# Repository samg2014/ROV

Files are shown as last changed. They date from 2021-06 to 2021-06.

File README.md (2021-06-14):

##*About This Project*
This respository is for all files related to modifications of the [Sea Perch](www.seaperch.org) ROV. The overall goals of this project are to:
* Make the vehicle controllable from a microcontroller or computer.
* Enable the vehicle to have the potential to be self contained. This includes:
  * Making the controller waterproof so it can be deployed on the vehicle,
  * Making the battery waterproof so it can go on the vehicle,
  * Writing autonomy scripts for the vehicle.
* Make the vehicle 'smart', including:
  * Autonomy, regardless of controller location (land or vehicle)
  * Sensor integration (IMUs...)
* Anything else we think of as we go.

##*Organization*
###Software Directory
The Software directory houses all of the code, Arduino or otherwise, associated with this project. It have two main subdirectories: Vehicle and Computer.
####Vehicle
The Vehicle subdirectory is for all sketches that are to be uploaded to the vehicle controller Arduino.
####Computer
The Computer subdirectory is for all support software that may exist. This could potentially be remote interfaces, wireless command sequence uploaders, command generators and much more.
###Electrical Directory
The Electrical directory is for schematics eagle design files and related to designing the vehicle controller. Additionally it should include parts lists and assembly processes if applicable.
###Hardware Directory
The Hardware Design directory is for potential CAD design files for the main structure of the vehicle.

##*Resources*
* [Google Drive folder](https://drive.google.com/folderview?id=0B45sdQ03G0k-UUpMSS1selFKa1k&usp=sharing) 
* [Sea Perch](www.seaperch.org) 
* [Sea Perch BOM](http://www.seaperch.org/Parts_List) (Note: requires free account) 
* [Sparkfun](www.sparkfun.com) (Parts)

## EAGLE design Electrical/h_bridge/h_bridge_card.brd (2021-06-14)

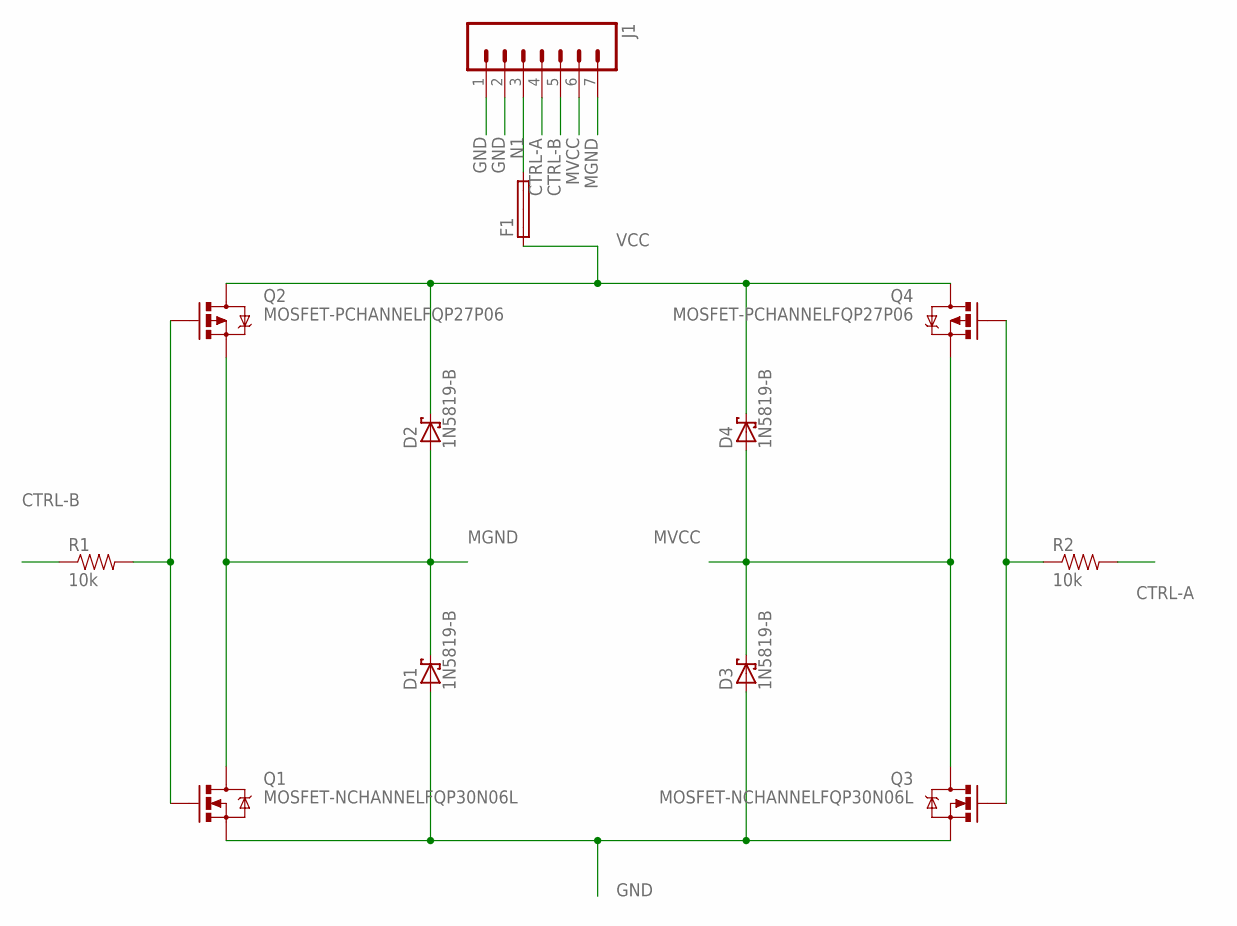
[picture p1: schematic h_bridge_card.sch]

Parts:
D1, D2, D3, D4: 1N5819-B; DO41-7.6
F1: SHK20L
J1: M07LOCK; 1X07_LOCK
Q1, Q3: MOSFET-NCHANNELFQP30N06L; TO220V
Q2, Q4: MOSFET-PCHANNELFQP27P06; TO220V
R1, R2: 10k; AXIAL-0.3

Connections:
CTRL-A: J1.4, R2.P$2 (2)
CTRL-B: J1.5, R1.P$1 (1)
GND: D1.A, D3.A, J1.1, J1.2, Q1.3 (S), Q3.3 (S)
MGND: D1.C, D2.A, J1.7, Q1.2 (D), Q2.3 (S)
MVCC: D3.C, D4.A, J1.6, Q3.2 (D), Q4.3 (S)
N1: F1.2A, J1.3
unnamed: Q3.1 (G), Q4.1 (G), R2.P$1 (1)
unnamed: Q1.1 (G), Q2.1 (G), R1.P$2 (2)
VCC: D2.C, D4.C, F1.1A, Q2.2 (D), Q4.2 (D)

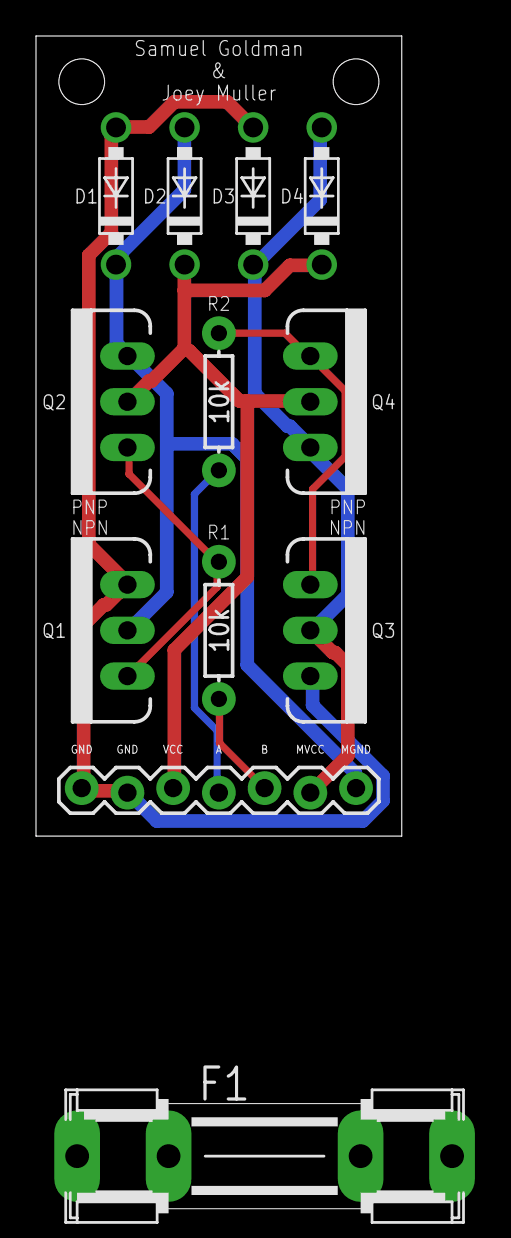
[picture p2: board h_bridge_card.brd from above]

Board: 2 copper layers, 20.3 x 44.5 mm, 12 parts (0 on the bottom side), 9 nets.

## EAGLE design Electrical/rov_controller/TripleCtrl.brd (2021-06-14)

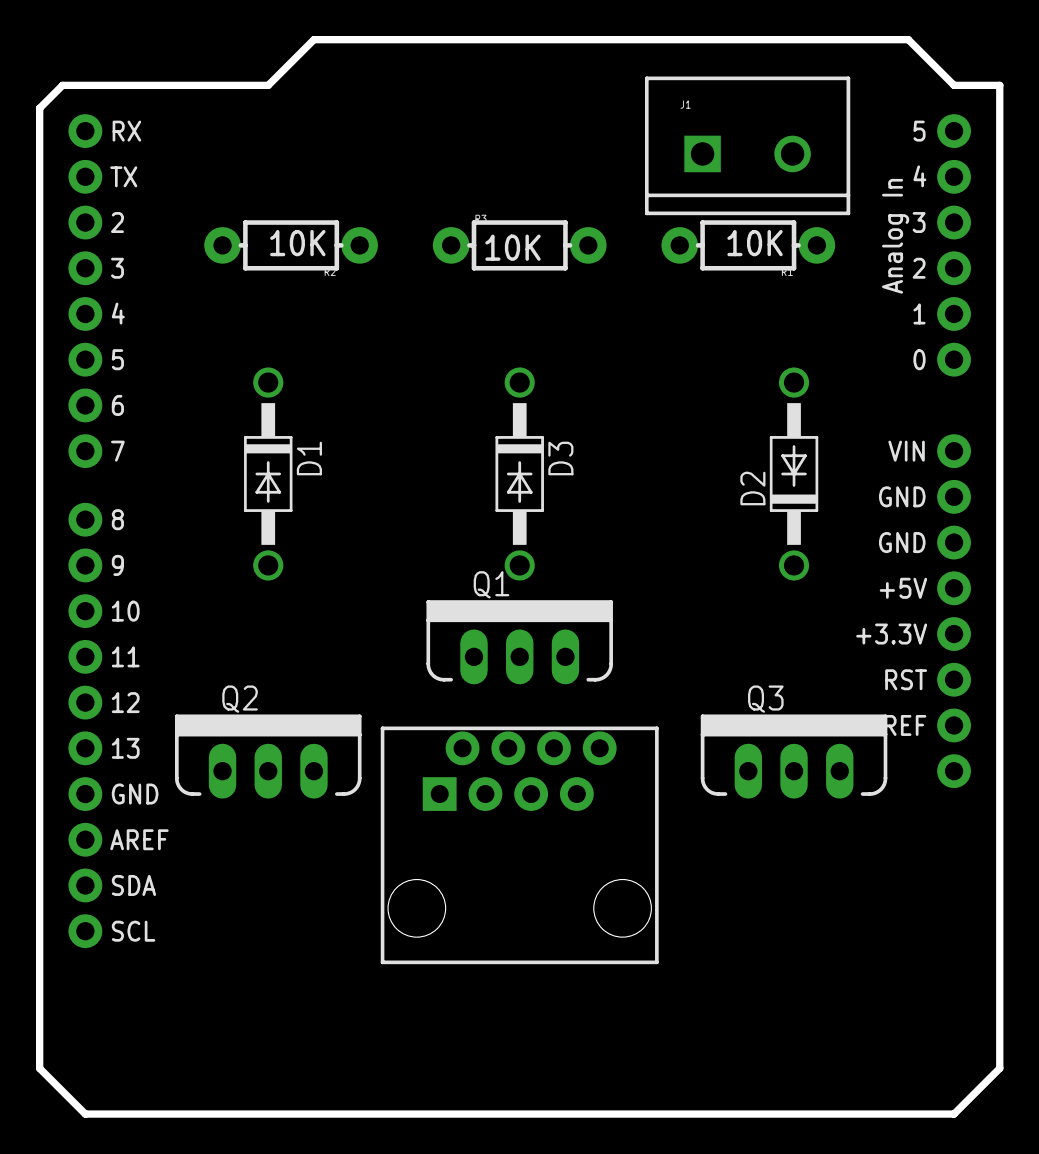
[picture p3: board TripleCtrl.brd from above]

Board: 2 copper layers, 53.3 x 59.7 mm, 12 parts (0 on the bottom side), 8 nets.

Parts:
D1, D2, D3: BA340A; DO41-10
J1: SCREWTERMINAL-5MM-2
J2: ARDUINO_R3_SHIELD; UNO_R3_SHIELD
J3: RJ45; RJ45-8
Q1, Q2, Q3: MOSFET-NCHANNELFQP30N06L; TO220V
R1, R2, R3: 10K; AXIAL-0.3-KIT

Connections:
unnamed: D1.C, D2.C, D3.C, J1.1, J3.1, J3.3, J3.4
unnamed: J1.2, J2.GND@0, Q1.3, Q2.3, Q3.3, R1.P$1, R2.P$1, R3.P$1
unnamed: D1.A, J3.2, Q1.2
unnamed: J2.D11, Q1.1, R1.P$2
unnamed: D2.A, J3.6, Q2.2
unnamed: D3.A, J3.5, Q3.2
unnamed: J2.D10, Q3.1, R3.P$2
unnamed: J2.D9, Q2.1, R2.P$2

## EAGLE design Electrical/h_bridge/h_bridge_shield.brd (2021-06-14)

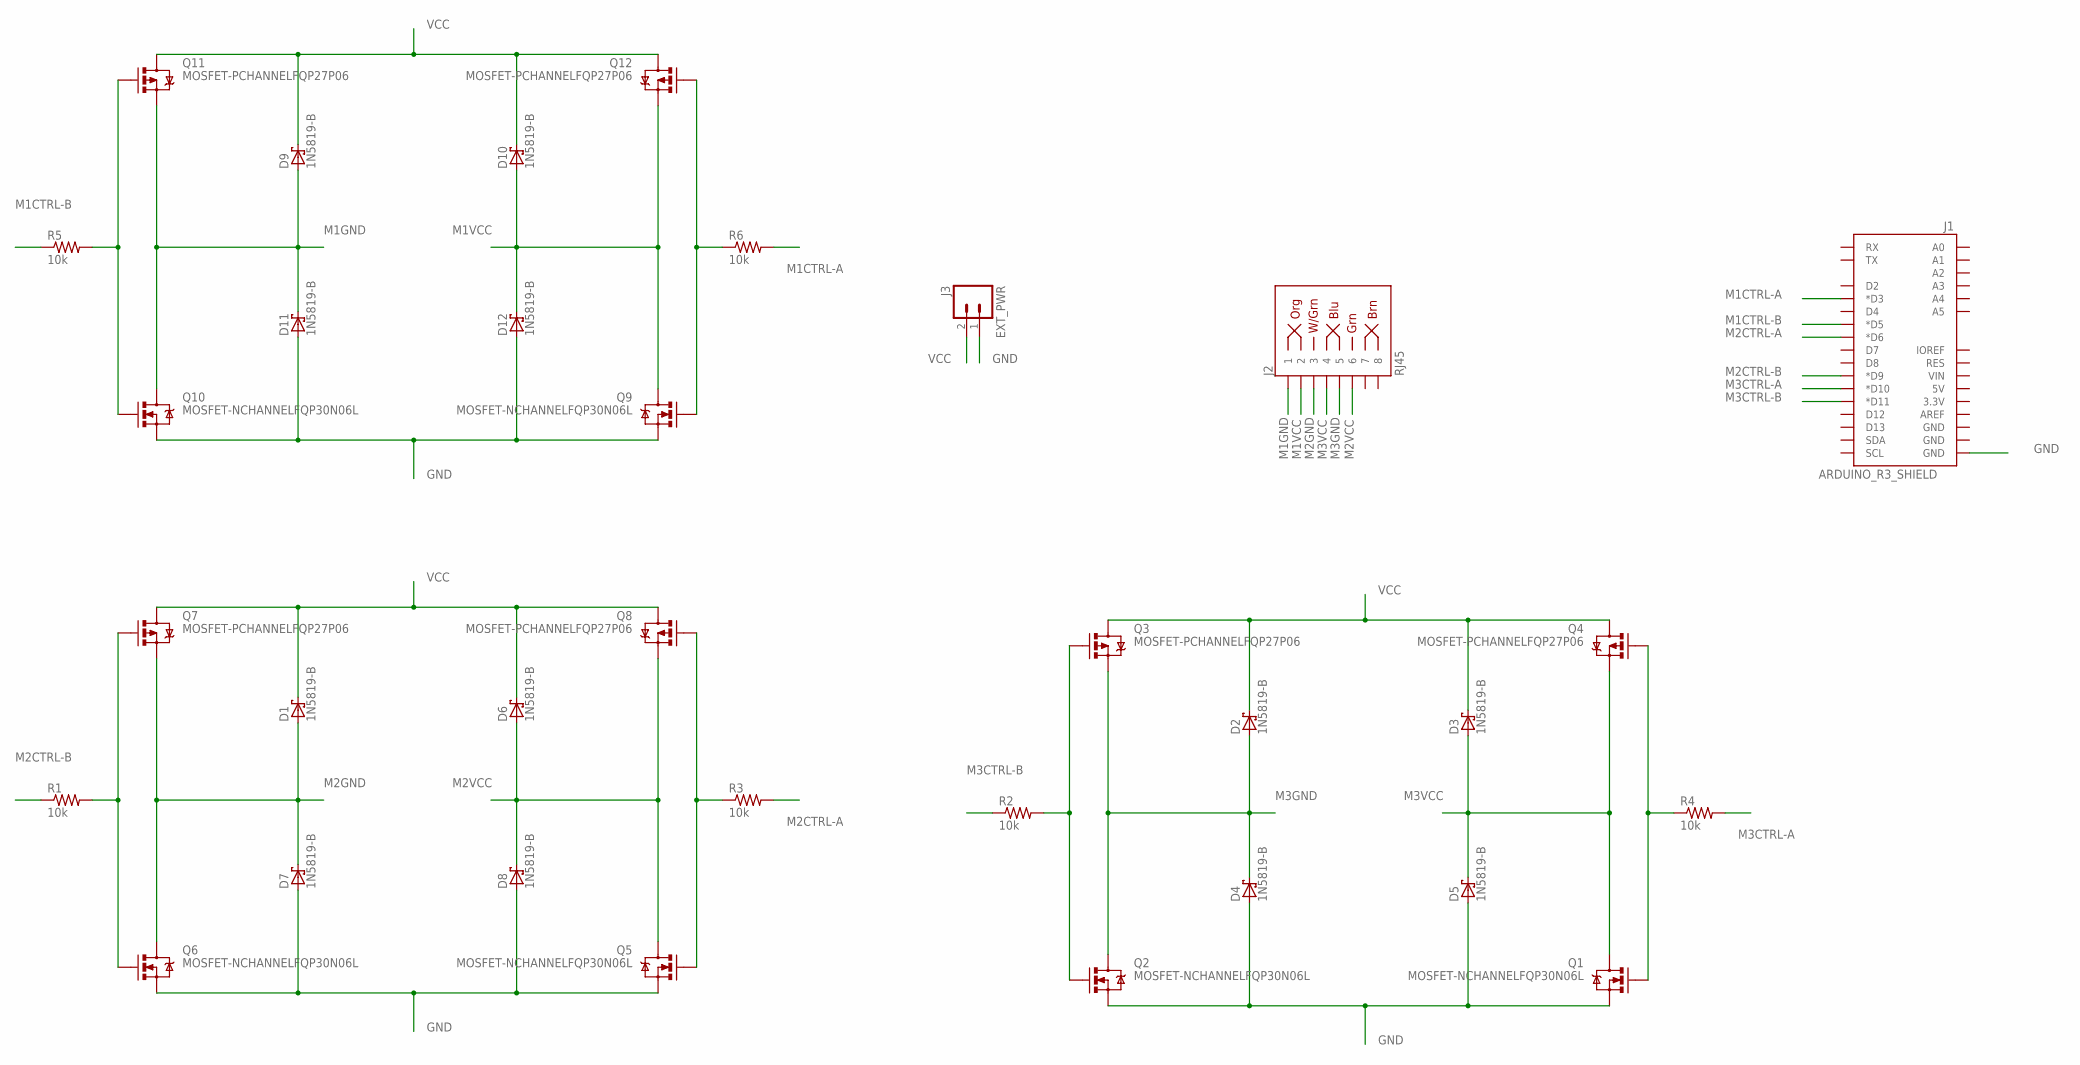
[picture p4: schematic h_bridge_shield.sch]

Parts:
D1, D2, D3, D4, D5, D6, D7, D8, D9, D10, D11, D12: 1N5819-B; DO41-7.6
J1: ARDUINO_R3_SHIELD; UNO_R3_SHIELD
J2: RJ45; RJ45-8
J3: EXT_PWR; JST-2-PTH-VERT
Q1, Q2, Q5, Q6, Q9, Q10: MOSFET-NCHANNELFQP30N06L; TO220V
Q3, Q4, Q7, Q8, Q11, Q12: MOSFET-PCHANNELFQP27P06; TO220V
R1, R2, R3, R4, R5, R6: 10k; AXIAL-0.3

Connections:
GND: D4.A, D5.A, D7.A, D8.A, D11.A, D12.A, J1.GND@0 (GND), J3.1, Q1.3 (S), Q2.3 (S), Q5.3 (S), Q6.3 (S), Q9.3 (S), Q10.3 (S)
M1CTRL-A: J1.D3 (*D3), R6.P$2 (2)
M1CTRL-B: J1.D5 (*D5), R5.P$1 (1)
M1GND: D9.A, D11.C, J2.1, Q10.2 (D), Q11.3 (S)
M1VCC: D10.A, D12.C, J2.2, Q9.2 (D), Q12.3 (S)
M2CTRL-A: J1.D6 (*D6), R3.P$2 (2)
M2CTRL-B: J1.D9 (*D9), R1.P$1 (1)
M2GND: D1.A, D7.C, J2.3, Q6.2 (D), Q7.3 (S)
M2VCC: D6.A, D8.C, J2.6, Q5.2 (D), Q8.3 (S)
M3CTRL-A: J1.D10 (*D10), R4.P$2 (2)
M3CTRL-B: J1.D11 (*D11), R2.P$1 (1)
M3GND: D2.A, D4.C, J2.5, Q2.2 (D), Q3.3 (S)
M3VCC: D3.A, D5.C, J2.4, Q1.2 (D), Q4.3 (S)
unnamed: Q5.1 (G), Q8.1 (G), R3.P$1 (1)
unnamed: Q6.1 (G), Q7.1 (G), R1.P$2 (2)
unnamed: Q9.1 (G), Q12.1 (G), R6.P$1 (1)
unnamed: Q10.1 (G), Q11.1 (G), R5.P$2 (2)
unnamed: Q1.1 (G), Q4.1 (G), R4.P$1 (1)
unnamed: Q2.1 (G), Q3.1 (G), R2.P$2 (2)
VCC: D1.C, D2.C, D3.C, D6.C, D9.C, D10.C, J3.2, Q3.2 (D), Q4.2 (D), Q7.2 (D), Q8.2 (D), Q11.2 (D), Q12.2 (D)

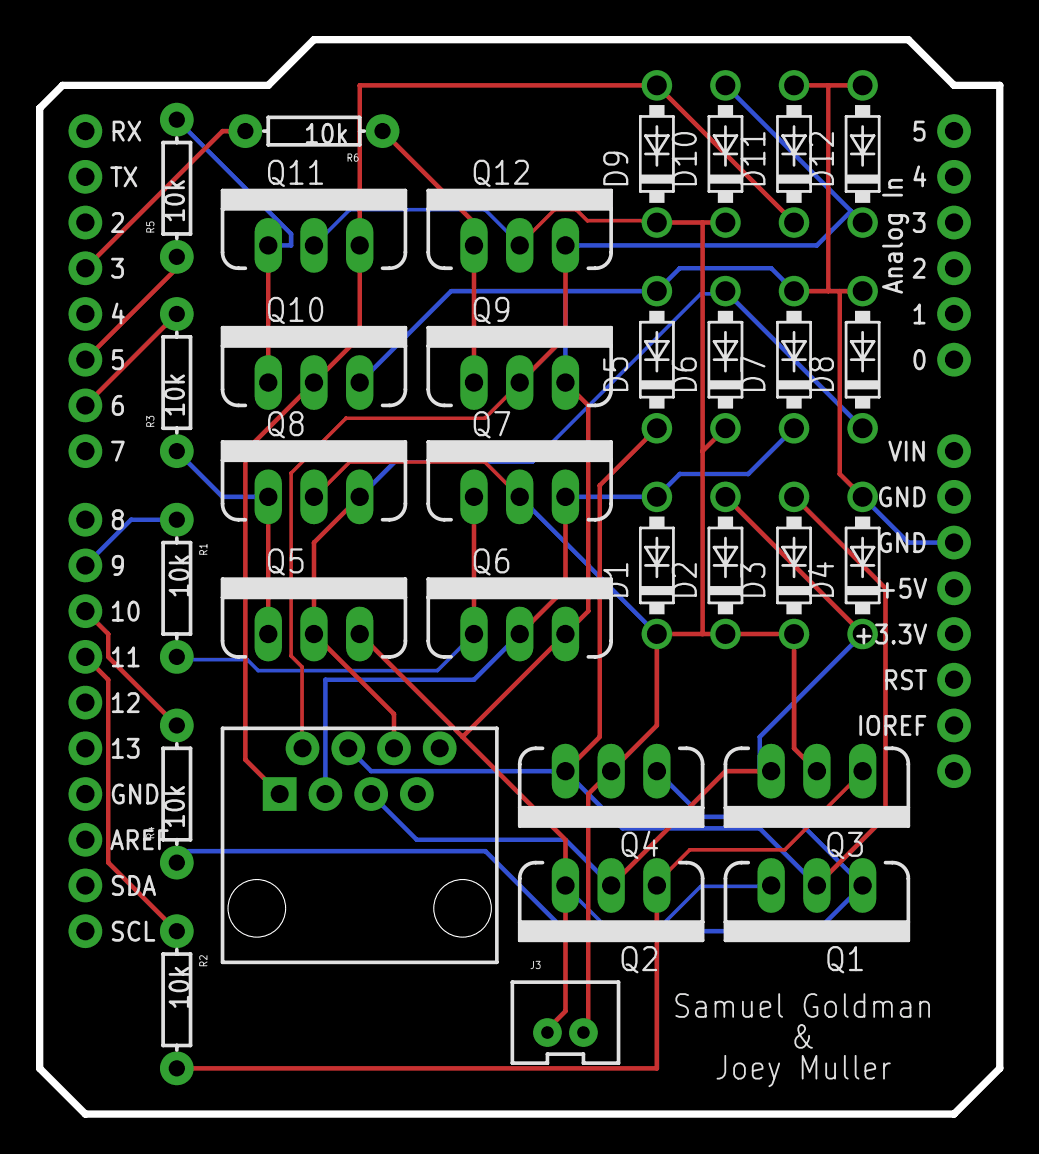
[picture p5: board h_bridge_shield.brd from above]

Board: 2 copper layers, 53.3 x 59.7 mm, 33 parts (0 on the bottom side), 20 nets.

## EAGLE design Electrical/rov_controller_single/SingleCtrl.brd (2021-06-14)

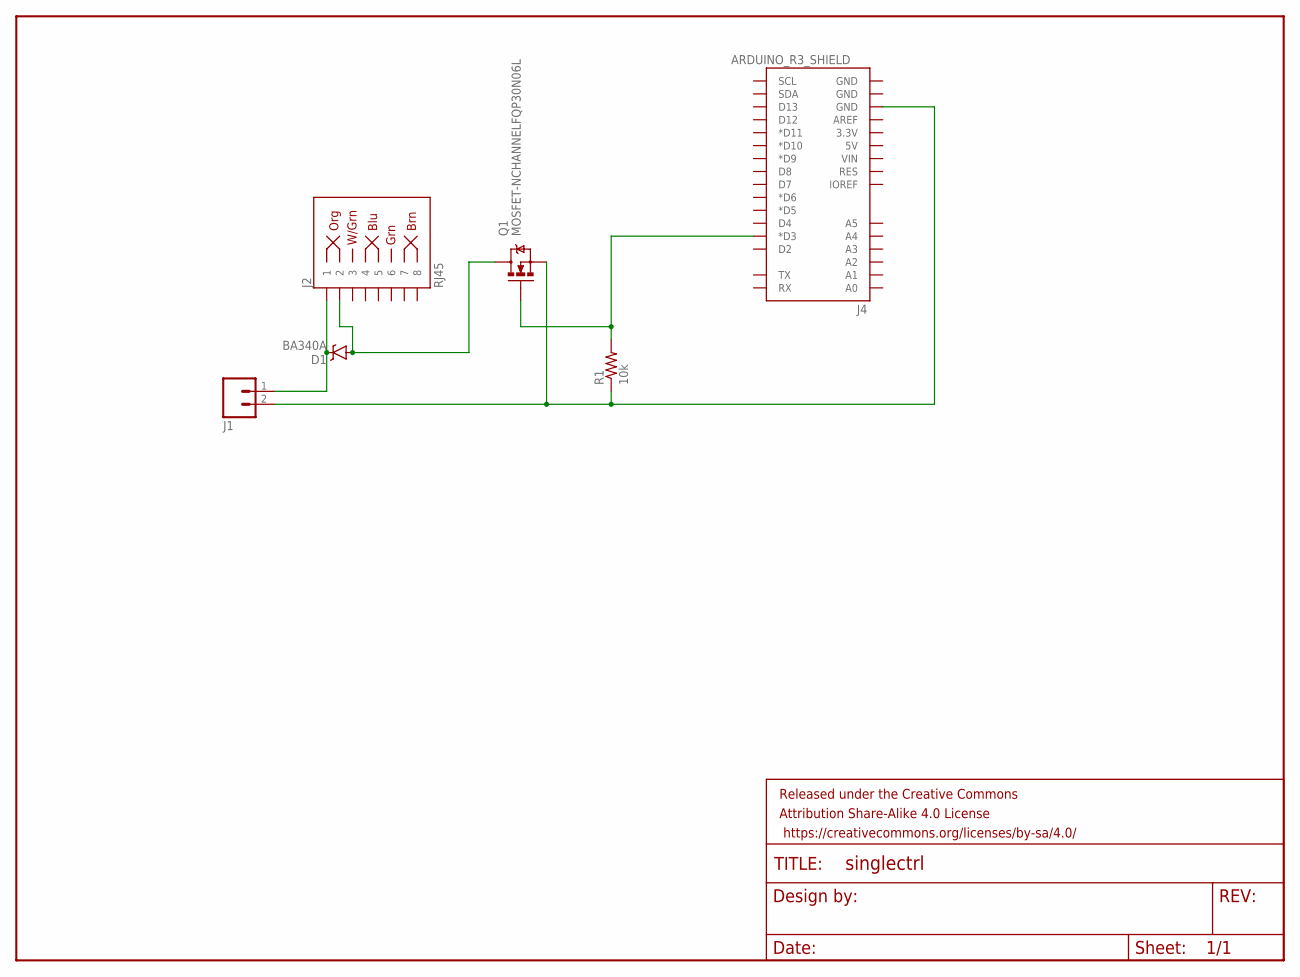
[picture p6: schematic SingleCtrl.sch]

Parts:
D1: BA340A; SMA-DIODE
FRAME1: FRAME-LETTER; CREATIVE_COMMONS
J1: M02JST-PTH-2; JST-2-PTH
J2: RJ45; RJ45-8
J4: ARDUINO_R3_SHIELD; UNO_R3_SHIELD
Q1: MOSFET-NCHANNELFQP30N06L; TO220V
R1: 10k; AXIAL-0.3

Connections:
unnamed: D1.C, J1.1, J2.1
unnamed: D1.A, J2.2, Q1.2 (D)
unnamed: J1.2, J4.GND@2 (GND), Q1.3 (S), R1.P$1 (1)
unnamed: J4.D3 (*D3), Q1.1 (G), R1.P$2 (2)

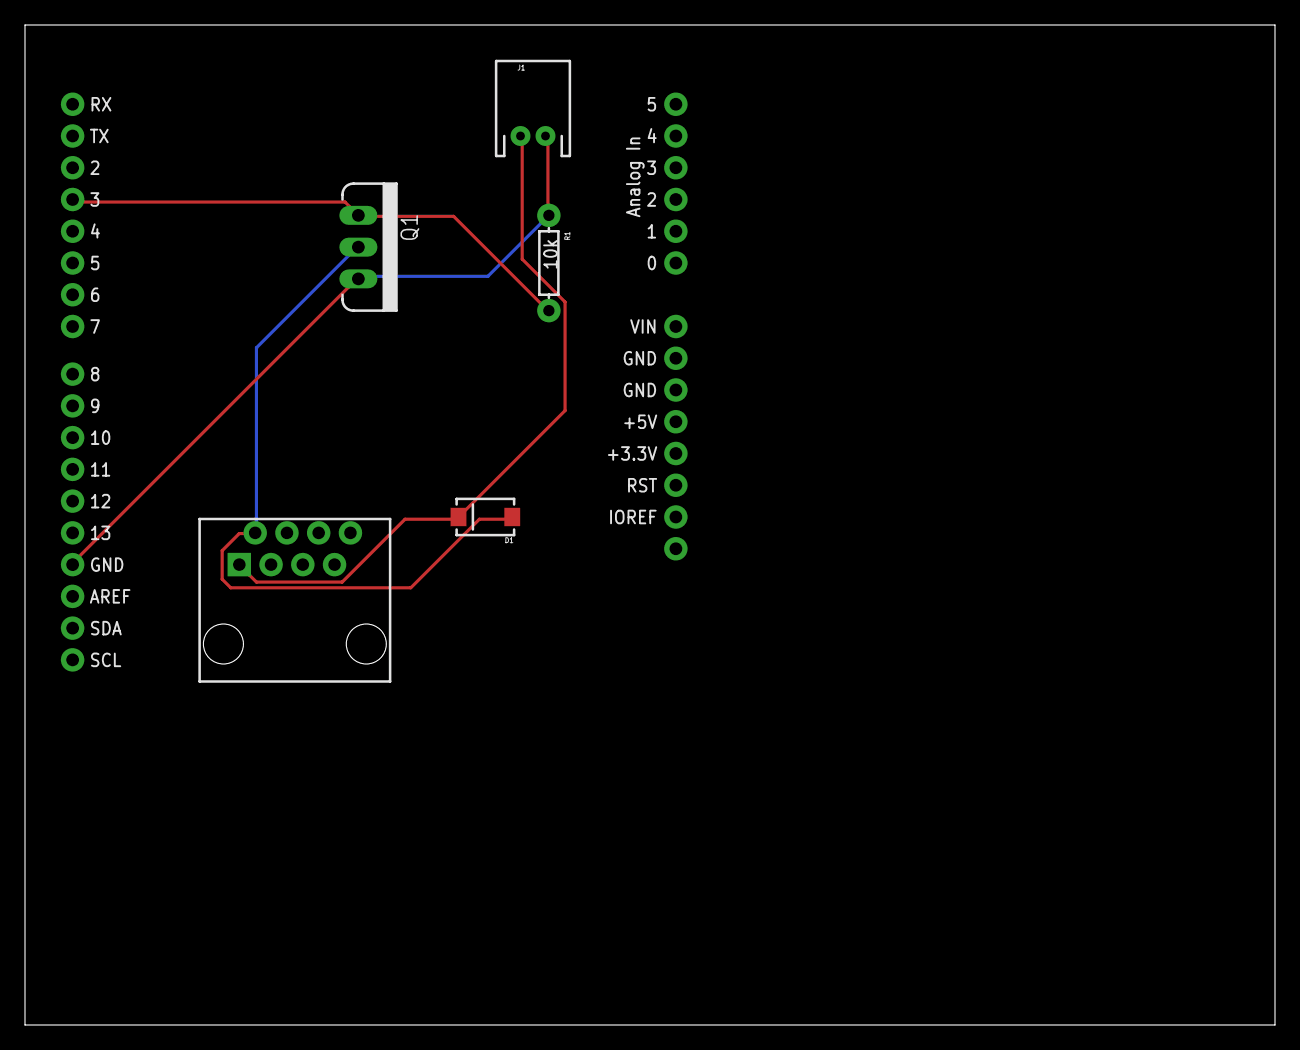
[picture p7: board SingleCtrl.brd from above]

Board: 2 copper layers, 100.0 x 80.0 mm, 7 parts (0 on the bottom side), 4 nets.

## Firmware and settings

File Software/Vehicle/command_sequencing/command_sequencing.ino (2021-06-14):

/**
   FILE NAME: command_sequencing
   AUTHOR: Samuel Goldman
   PURPOSE: run the vehicle by sending a sequence of commands
            to be run later.
*/

String inputString = "";         // a string to hold incoming data
boolean stringComplete = false;  // whether the string is complete

// Flags to determine what run mode the vehicle is in
bool EDIT_MODE = false;
bool RUN_NORM = false;
bool RUN_DEBUG = false;

// A list of commands to be executed
String COMMANDS[50];
int COMMANDS_LENGTH = 0; // How many commands are actually in the list

// Index to execute now
int EXECUTE_INDEX = -1;

void setup() {
  // initialize serial:
  Serial.begin(9600);

  // reserve 200 bytes for the inputString:
  inputString.reserve(200);

  // Setup pins for motor control
  pinMode(9, OUTPUT);
  pinMode(10, OUTPUT);
  pinMode(11, OUTPUT);
}

void loop() {
  // Handle new input
  if (stringComplete) {

    // Enter edit mode if possible
    if (inputString == "--edit") {
      if (RUN_NORM == true || RUN_DEBUG == true) {
        Serial.println("The program is running. To edit it, run '--halt'.");
      } else if (EXECUTE_INDEX != -1) {
        Serial.println("The program is paused. To edit it, run '--halt'.");
      } else {
        EDIT_MODE = true;
        Serial.println("Entering program editer...");
      }
    }

    // Quit the command sequence editor
    if (inputString == "--quit") {
      EDIT_MODE = false;
      Serial.println("Exiting program editer...");
    }

    // Handle the execute command
    if (inputString.startsWith("--execute")) {
      if (EDIT_MODE == true) {
        Serial.println("In edit mode, cannot execute now!");
      }
      else if (RUN_NORM == true) {
        Serial.println("Already running normally!");
      }
      else if (RUN_DEBUG == true) {
        Serial.println("Already running in debug mode!");
      }
      else {
        int index = inputString.indexOf(" ");
        if (index == -1) {
          if (EXECUTE_INDEX == -1)
            EXECUTE_INDEX = 0;
          Serial.println((String)"Starting execution at index=" + EXECUTE_INDEX + "...");
          RUN_NORM = true;
        }
        else {
          int temp = inputString.substring(index + 1).toInt();
          if (temp > COMMANDS_LENGTH - 1) {
            Serial.println("Starting index out of bounds!");
          } else {
            EXECUTE_INDEX = temp;
            Serial.println((String)"Starting execution at index=" + EXECUTE_INDEX + "...");
            RUN_NORM = true;
          }
        }
      }
    }

    // Execute commands in debug mode
    if (inputString.startsWith("--debug")) {
      if (EDIT_MODE == true) {
        Serial.println("In edit mode, cannot execute now!");
      }
      else if (RUN_NORM == true) {
        Serial.println("Already running normally!");
      }
      else if (RUN_DEBUG == true) {
        Serial.println("Already running in debug mode!");
      }
      else {
        int index = inputString.indexOf(" ");
        if (index == -1) {
          if (EXECUTE_INDEX == -1)
            EXECUTE_INDEX = 0;
          Serial.println((String)"Starting execution at index=" + EXECUTE_INDEX + "...");
          RUN_DEBUG = true;
        }
        else {
          int temp = inputString.substring(index + 1).toInt();
          if (temp > COMMANDS_LENGTH - 1) {
            Serial.println("Starting index out of bounds!");
          } else {
            EXECUTE_INDEX = temp;
            Serial.println((String)"Starting execution at index=" + EXECUTE_INDEX + "...");
            RUN_DEBUG = true;
          }
        }
      }
    }

    if (inputString == "--halt") {
      Serial.println("Halting execution...");
      RUN_NORM = false;
      RUN_DEBUG = false;
      EXECUTE_INDEX = -1;
    }

    if (inputString == "--pause") {
      Serial.println("Pausing execution...");
      RUN_NORM = false;
      RUN_DEBUG = false;
    }

    if (inputString == "--print") {
      int i;
      Serial.println("\tStart Program");
      for (i = 0; i < COMMANDS_LENGTH; i++) {
        Serial.println(COMMANDS[i]);
      }
      Serial.println("\tEnd Program");
    }

    // Add a command if in edit mode and there is enough space
    if (inputString.startsWith("--add")) {
      if (EDIT_MODE) {
        String command = inputString.substring(inputString.indexOf(" ") + 1);
        if (COMMANDS_LENGTH < 50) {
          COMMANDS[COMMANDS_LENGTH] = command;
          COMMANDS_LENGTH++;

          Serial.println((String)"Added command " + command + " for a total of " + COMMANDS_LENGTH + " commands...");
        } else {
          Serial.println("Maximum number of commands (50) has been exeeded!");
        }
      } else {
        Serial.println("Not in edit mode!");
      }
    }

    inputString = "";
    stringComplete = false;
  }

  // If executing, execute the next command
  if (RUN_NORM || RUN_DEBUG) {
    run_next();
  }
}

void run_next() {
  String current = COMMANDS[EXECUTE_INDEX];

  // Handle the different commands:

  if (current.startsWith("INIT")) {
    int pin = current.substring(current.indexOf("-") + 1).toInt();
    print_debug((String) "Initializing pin " + pin + "...");
    pinMode(pin, OUTPUT);
  }
  if (current.startsWith("PRINT")) {
    Serial.println("PRINT: " + current.substring(current.indexOf("-") + 1));
  }
  if (current.startsWith("PAUSE")) {
    int pause = current.substring(current.indexOf("-") + 1).toInt();
    print_debug((String) "Pausing for " + pause + " milliseconds...");
    delay(pause);
  }
  if (current.startsWith("DIGSET")) {
    String values = current.substring(current.indexOf("-") + 1);
    int pin = values.substring(0, values.indexOf("-")).toInt();
    String value = values.substring(values.indexOf("-") + 1);
    if (value == "HIGH") {
      print_debug((String) "Setting pin " + pin + " to " + value + "...");
      digitalWrite(pin, HIGH);
    }
    if (value == "LOW") {
      print_debug((String) "Setting pin " + pin + " to " + value + "...");
      digitalWrite(pin, LOW);
    }
  }
  if (current.startsWith("ALGSET")) {
    String values = current.substring(current.indexOf("-") + 1);
    int pin = values.substring(0, values.indexOf("-")).toInt();
    int value = values.substring(values.indexOf("-") + 1).toInt();
    if (value >= 0 && value <= 255) {
      print_debug((String) "Setting pin " + pin + " to " + value + "...");
      analogWrite(pin, value);
    }
  }
  if (current.startsWith("GOTO")) {
    int goTo = current.substring(current.indexOf("-") + 1).toInt();
    if (goTo < COMMANDS_LENGTH) {
      EXECUTE_INDEX = goTo;
      print_debug((String) "Going to " + goTo + "...");
      return;
    }
    else {
      print_debug((String) "Cannot go to " + goTo + "...");
    }
  }

  if (EXECUTE_INDEX + 1 < COMMANDS_LENGTH) {
    EXECUTE_INDEX ++;
  } else {
    print_debug("Reached the end of the program...");
    EXECUTE_INDEX = -1;
    RUN_NORM = false;
    RUN_DEBUG = false;
  }

}

void print_debug(String val) {
  if (RUN_DEBUG)
    Serial.println(val);
}


// Read in from serial
void serialEvent() {
  while (Serial.available()) {
    // get the new byte:
    char inChar = (char)Serial.read();
    if (inChar == ';') {
      stringComplete = true;
      return;
    }
    // add it to the inputString:
    inputString += inChar;
  }
}

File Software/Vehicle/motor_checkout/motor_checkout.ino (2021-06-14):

/**
 * FILE NAME: motor_checkout
 * AUTHOR: Samuel Goldman
 * PURPOSE: test all three motors each controlled via single 
 *          mosfet circuits.
 */
 
const int RIGHT_MOTOR_PIN = 9;
const int LEFT_MOTOR_PIN = 10;
const int DOWN_MOTOR_PIN = 11;

void setup() {
  // Setup the motor control pins for output
  pinMode(RIGHT_MOTOR_PIN, OUTPUT);
  pinMode(LEFT_MOTOR_PIN, OUTPUT);
  pinMode(DOWN_MOTOR_PIN, OUTPUT);

  // Set all motors to full speed
  analogWrite(RIGHT_MOTOR_PIN, 255);
  analogWrite(LEFT_MOTOR_PIN, 255);
  analogWrite(DOWN_MOTOR_PIN, 255);

  // Run all motors for 2.5 seconds
  delay(2500);

  // Stop all motors to conclude testing
  analogWrite(RIGHT_MOTOR_PIN, 0);
  analogWrite(LEFT_MOTOR_PIN, 0);
  analogWrite(DOWN_MOTOR_PIN, 0);
}

void loop() {
  // Nothing to do
}

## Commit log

2016-08-07 Adding three arduino files for testing the bot.
2021-06-14 Add old changes
    [SingleCtrl.brd, SingleCtrl.sch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]

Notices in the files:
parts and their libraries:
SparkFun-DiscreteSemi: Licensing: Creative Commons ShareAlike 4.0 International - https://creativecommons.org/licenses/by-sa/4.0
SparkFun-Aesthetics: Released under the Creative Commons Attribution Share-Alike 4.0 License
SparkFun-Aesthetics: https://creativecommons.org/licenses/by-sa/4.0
